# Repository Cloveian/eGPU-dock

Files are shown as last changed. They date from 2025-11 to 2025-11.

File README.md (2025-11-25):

## Goal

Create a single-board Thunderbolt 4 dock with:

* PCIe x4 GPU slot
* M.2 NVMe slot
* Lots of USB Ports
* Fast Ethernet
* 60–100 W Power Delivery (PD)
* Single voltage input

---

## Design Constraints / Features

### Wanted Features

* **Thunderbolt 4 (TB4) connection**

  * One TB4 port dedicated to PCIe tunneling for GPU
  * One TB4 port dedicated to M.2 NVMe, USB, and Ethernet
* **PCIe 4.0 x4 slot**

  * Maximum lanes available over TB4 (for GPU)
* **M.2 NVMe slot**

  * PCIe Gen4 x2
* **Power Delivery (PD)**

  * 60–100 W to laptop over TB4
* **USB Hub**

  * 4 USB-C ports
  * 4 USB-A 3.x ports
* **Single Voltage Input**

  * Powers all components: TB4 controller, USB hub, NVMe, optional GPU rails

---

## Notes / Design Considerations

* **PCIe Lane Allocation**

  * TB4 Port 1: x4 lanes → GPU
  * TB4 Port 2: x4 lanes → M.2 NVMe, USB, and Ethernet
* **Power Distribution**

  * Hub powered from 5 V regulated rail
  * NVMe powered from 3.3 V regulated rail
  * Optional GPU rails from main input if using external connector
* **High-Speed Signal Integrity**

  * Controlled impedance for PCIe and TB4 differential pairs
  * Length matching for PCIe lanes
* **Thermal Management**

  * Heatsink for ASM2464PD TB4 controllers
  * Airflow for GPU and NVMe
  * Optional fan headers
* **User QoL Features**

  * LED indicators: TB4 link, GPU detected, NVMe active, USB hub power/activity
  * Hot-plug detection and optional soft-reset for GPU/NVMe
  * Debug/test points for PCIe, USB lanes, and PD monitoring

---

## Component Selection

| Component | Model / Notes |
| --- | --- |
| TB4 Controller | 2x ASM2464PD |
| PCIe Fanout Chip (USB+2.5G MAC) | PCI11414C |
| 2.5GbE Transceiver | TBD |
| USB Hub(S) | 1x USB7216C + 1x USB7206C |
| PD+USB-C negotiation | TBD |
| Voltage Regulators | Switching / Linear as required |

<!--
[https://files.slop.gay/pub/docs/Asmedia/ASM2464PD-X/](https://files.slop.gay/pub/docs/Asmedia/ASM2464PD-X/)
-->

---

## Data Flow

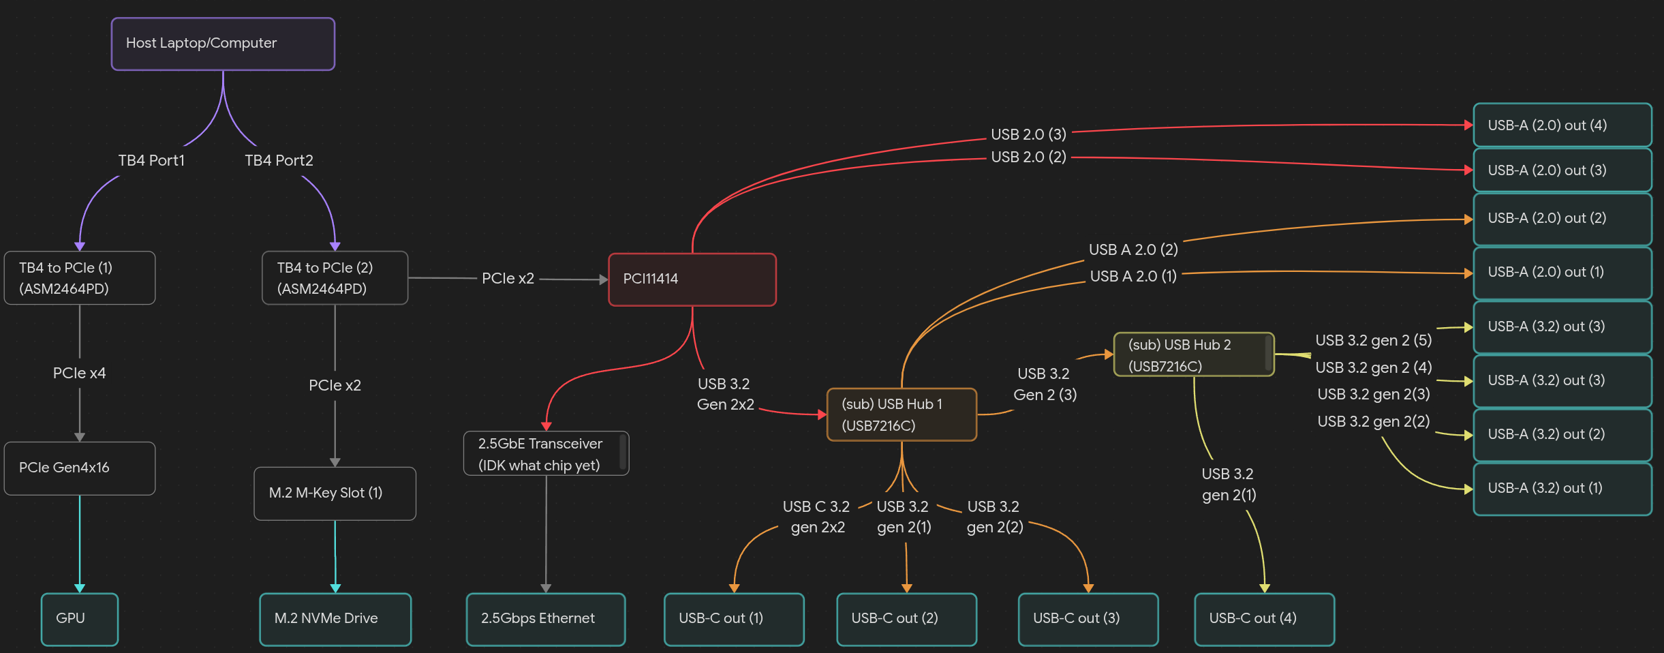
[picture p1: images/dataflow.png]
Data Flow Chart


---
<!-- 
## Electrical / Power Planning

* Input Voltage: 12–20 V (regulated for all components)
* Power Budget:

  * GPU: external connector
  * NVMe: 3.3 V / 5 V
  * USB hub: 5 V, max 900 mA per USB-A port, PD for USB-C ports
* PD Output: 60–100 W to host laptop
* Overcurrent / overvoltage protection per rail

---
-->

## Mechanical / PCB Planning

#### Layer Stackup
| Layer | Type | Primary Use | Key PI/SI Note |
|---|---|---|---|
| L1 | Signal | HS (TB4, PCIe) | Microstrip. Route shortest high-speed traces here. |
| L2 | GND | Solid Ground | Unified Ground. Primary reference for L1 & L3. |
| L3 | Signal | HS (TB4, PCIe) | Stripline. Route longest critical differential pairs. Ref: L2/L4. |
| L4 | GND | Solid Ground | Unified Ground. Shields top signals from the power core. |
| L5 | Signal | HS (USB 3.2, 2.5GbE) | Stripline. Secondary high-speed routing layer. Ref: L4/L6. |
| L6 | PWR | 12V GPU Rail | CRITICAL: Use 2 oz copper. Sandwiched by L5 & L7 GND for isolation. |
| L7 | GND | Solid Ground | Unified Ground. Isolates 12V from 5V. |
| L8 | PWR | 5V System Rail | Sandwiched by L7 & L9 GND. Consider 2 oz copper if current is high. |
| L9 | GND | Solid Ground | Unified Ground. Isolates 5V from 3.3V. |
| L10 | PWR | 3.3V Logic Rail | Sensitive. Ideal layer for small Analog Power Island split. |
| L11 | GND | Solid Ground | Unified Ground. Shields core from bottom signals. |
| L12 | Signal | LS (I2C, SPI) | Stripline. Good for noisy low-speed digital signals. |
| L13 | Signal | LS (GPIOs) | Stripline. General-purpose routing. |
| L14 | Signal | LS (Audio) | Stripline. Keep sensitive audio traces here. |
| L15 | Signal | POL Islands / Spare | Ideal for local low-voltage power islands (1.050V, 1.900V). |
| L16 | Signal | Component Breakout | Microstrip. Used for lower speed/density connections. |

---
<!--
## Notes / To-Do

* Final PCIe lane allocation plan
* USB hub layout (mix of USB-C / USB-A)
* 3D case design / airflow
* PCB stackup, layer allocation
* Component sourcing & cost analysis
* Firmware testing (hot-plug, soft-reset, PD negotiation)

---
-->

<!--
## References

* ASM2464PD datasheet
* CYUSB3304 datasheet
* TPS65987DDJ datasheet
* PCIe / Thunderbolt routing guides
* Voltage regulator datasheets

---
-->

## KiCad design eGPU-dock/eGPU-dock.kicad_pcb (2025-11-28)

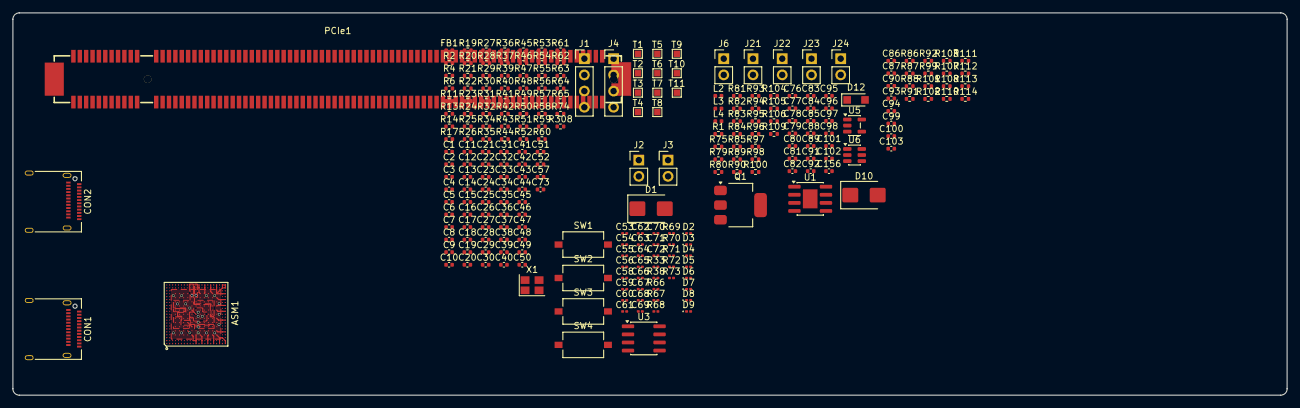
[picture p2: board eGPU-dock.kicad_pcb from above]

Board: 16 copper layers, 200.0 x 60.0 mm, 253 parts (0 on the bottom side), 145 nets.

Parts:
ASM1: ASM2464PDX
C1, C2, C3, C9, C10, C11, C15, C16, C17, C88, C89: 2.2UF/6.3V; C_0402_1005Metric
C4, C5, C6, C12, C13, C14, C18, C19, C20, C21: 10UF/6.3V; C_0402_1005Metric
C7, C78, C79: 22UF/6.3V; C_0402_1005Metric
C8, C23, C26, C27, C30, C31, C34, C35, C39: 0.22UF/10V; C_0402_1005Metric
C22, C24, C25, C28, C29, C32, C33, C36, C37, C40, C41, C42, C43, C44, C45, C46: 0.22UF/6.3V; C_0402_1005Metric
C38: 10PF/50V; C_0402_1005Metric
C47, C48: 0.22UF/16V; C_0402_1005Metric
C49, C50, C51, C52: 1UF/10V; C_0402_1005Metric
C53, C54: 220PF/50V; C_0201_0603Metric
C55, C56, C58, C59, C60, C61: 0.1UF/25V; C_0201_0603Metric
C57, C73, C81, C82, C84, C85, C92, C101, C156: 0.1UF/16V; C_0402_1005Metric
C62, C63, C64, C65, C69, C70, C71, C72: 0.33UF/25V; C_0201_0603Metric
C66, C67: 0.1UF/16V; C_0201_0603Metric
C68: 1UF/16V; C_0201_0603Metric
C76, C77: 15PF/50V; C_0402_1005Metric
C80, C83: 10UF/16V; C_0402_1005Metric
C86, C87, C90, C93, C94, C99, C100, C103: 0.22u; C_0402_1005Metric
C91: 0.1UF/50V; C_0402_1005Metric
C95, C96: 22UF/10V; C_0402_1005Metric
C97, C98: 10UF/25V; C_0402_1005Metric
C102: 3300PF/50V; C_0402_1005Metric
CON1, CON2: USB_C_Plug; USB_C_Receptacle_Amphenol_12401610E4-2A
D1, D10: SR34; D_SMB
D2, D3, D4, D5, D6, D7, D8, D9: ESD150; D_0201_0603Metric
D12: B130LAW; Nexperia_CFP3_SOD-123W
FB1: 5nF; L_0402_1005Metric
J1, J4: Conn_01x04; PinHeader_1x04_P2.54mm_Vertical
J2, J3, J6, J21, J22, J23, J24: Conn_01x02; PinHeader_1x02_P2.54mm_Vertical
L2, L3: 2.2UH; L_0402_1005Metric
L4: 10UH; L_0402_1005Metric
PCIe1: PCIexpress_x16; CONN-SMD_164P-P1.00_X1611WVS-164-9TV30
Q1: GS1117AXF; SOT-223
R1: 2.2KΩ; R_0402_1005Metric
R2: 20Ω; R_0402_1005Metric
R4, R11, R17, R19, R25, R26, R29, R31, R32, R34, R36, R37, R41, R54, R55, R59, R63, R64, R65, R74, R75, R84, R87, R88, R91, R92, R93, R94, R95, R96, R97, R99, R101, R102, R103, R104, R105, R107, R108, R110, R111, R112, R113, R114, R308: 0Ω; R_0402_1005Metric
R6, R20, R21, R24, R27, R28, R30, R81, R85, R100: 100KΩ; R_0402_1005Metric
R13, R43, R44, R45, R46, R47, R48, R49, R50, R51, R52, R53, R56, R57, R58, R61, R62: 4.7KΩ; R_0402_1005Metric
R14, R22, R23, R35: 1KΩ; R_0402_1005Metric
R33, R38: 0Ω; R_0201_0603Metric
R39, R40: 2MΩ; R_0402_1005Metric
R42: 12.1KΩ; R_0402_1005Metric
R60, R106: 10KΩ; R_0402_1005Metric
R66, R67, R68, R69, R70, R71, R72, R73: 220KΩ; R_0201_0603Metric
R79: 330KΩ; R_0402_1005Metric
R80, R89: 150KΩ; R_0402_1005Metric
R82: 165Ω; R_0402_1005Metric
R83: 100Ω; R_0402_1005Metric
R86: 4.7kΩ; R_0402_1005Metric
R90: 180KΩ; R_0402_1005Metric
R98: 28KΩ; R_0402_1005Metric
R109: 7.5KΩ; R_0402_1005Metric
SW1, SW2, SW3, SW4: SW_Push; SW_Tactile_SPST_NO_Straight_CK_PTS636Sx25SMTRLFS
T1, T2, T3, T4, T5, T6, T7, T8, T9, T10, T11: TestPoint; TestPoint_Pad_1.0x1.0mm
U1: MP2307DN; SOIC-8-1EP_3.9x4.9mm_P1.27mm_EP2.29x3mm
U3: W25X20CLSN; SOIC-8_3.9x4.9mm_P1.27mm
U5: RT8059; TSOT-23-5
U6: ID8225B-ADA60; SOT-23-6
X1: 25 Mhz; Crystal_SMD_Abracon_ABM8AIG-4Pin_3.2x2.5mm

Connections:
3V3OUT_1D: C80.2, C81.2, Q1.2 (OUT), Q1.4 (Vout), R83.1, R84.2
+1.05V_PG: R75.1, U6.5 (PG)
+3.3V: J6.1, R86.1
+3.3V_PCIE: PCIe1.A9 (+3.3V), PCIe1.A10 (+3.3V), PCIe1.B8 (+3.3V)
+5V_BUS: C82.2, C83.2, C88.2, C89.2, D1.1 (K), J2.1, Q1.3 (IN), R54.2, R55.1, R81.1, R85.1, R95.1, U5.4 (VIN), U6.4 (VIN)
+5V_BUS_CON: C55.1, C56.1, C58.1, C59.1, C60.1, C61.1, C66.2, C67.2, CON1.A4 (VBUS), CON1.A9 (VBUS), CON1.B4 (VBUS), CON1.B9 (VBUS), D1.2 (A), J2.2, R54.1, R55.2, R57.2, R94.1
+12V_AD: J23.1, R104.1
+12V_ATX: J23.2, J24.2
+12V_PCIE: PCIe1.A2 (+12V), PCIe1.A3 (+12V), PCIe1.B1 (+12V), PCIe1.B2 (+12V), PCIe1.B3 (+12V)
/GPU/GPU1/CLONE: C50.2, R27.2, R29.1, SW3.1
/GPU/GPU1/ERASE: C49.2, R24.2, R25.1, R26.1, SW1.1
/GPU/GPU1/I2C_INT_PDC: J3.1, R63.1
/GPU/GPU1/I2C_VCC_P: J4.1, R74.1
/GPU/GPU1/VBUS_CON: C68.2, R57.1, R59.2, R60.2
/GPU/GPU2/1V8_EN: C84.2, R85.2, U5.1 (EN)
/GPU/GPU2/+1.05V_EN: C85.2, R81.2, U6.1 (EN)
/GPU/GPU2/FB_1V8: C77.1, R79.2, R89.1, U5.5 (OUT)
/GPU/GPU2/FB_3V3_1D: Q1.1 (ADJ/GND), R82.1, R83.2
/GPU/GPU2/PS_ON#: C156.2, J22.1, R1.2
/GPU/GPU3/PCIe_TX0_C+: C86.2, PCIe1.B14 (PETp0)
/GPU/GPU3/PCIe_TX0_C-: C87.2, PCIe1.B15 (PETn0)
/GPU/GPU3/PCIe_TX1_C+: C90.2, PCIe1.B19 (PETp1)
/GPU/GPU3/PCIe_TX1_C-: C93.2, PCIe1.B20 (PETn1)
/GPU/GPU3/PCIe_TX2_C+: C94.2, PCIe1.B23 (PETp2)
/GPU/GPU3/PCIe_TX2_C-: C99.2, PCIe1.B24 (PETn2)
/GPU/GPU3/PCIe_TX3_C+: C100.2, PCIe1.B27 (PETp3)
/GPU/GPU3/PCIe_TX3_C-: C103.2, PCIe1.B28 (PETn3)
AD2: C95.2, C96.2, D10.2 (A), L4.2, R96.1, R97.1, R98.1
CC1: ASM1.AA6 (CC1), C54.2, R33.1
CC1_C: CON1.A5 (CC), R33.2
CC2: ASM1.Y6 (CC2), C53.2, R38.1
CC2_C: CON1.B5 (VCONN), R38.2
GND: ASM1.AA1 (GNDA), ASM1.AA2 (GNDA), ASM1.AA5 (GNDA), ASM1.AA9 (GNDA), ASM1.AA12 (GNDA), ASM1.AA14 (GNDA), ASM1.AA16 (GNDA), ASM1.AA18 (GNDA), ASM1.AA20 (GNDA), ASM1.AA21 (GNDA), ASM1.D4 (GND), ASM1.D5 (GND), ASM1.D11 (GND), ASM1.D17 (GND), ASM1.D18 (GND), ASM1.E4 (GND), ASM1.E5 (GND), ASM1.E17 (GND), ASM1.E18 (GND), ASM1.F4 (GND), ASM1.F5 (GND), ASM1.F8 (GND), ASM1.F17 (GND), ASM1.F18 (GND), ASM1.H4 (GND), ASM1.H8 (GND), ASM1.H17 (GND), ASM1.H18 (GND), ASM1.J4 (GND), ASM1.J5 (GND), ASM1.J6 (GND), ASM1.J11 (GND), ASM1.K2 (GND), ASM1.L1 (GNDA), ASM1.L2 (GNDA), ASM1.L4 (GNDA), ASM1.L5 (GNDA), ASM1.L9 (GND), ASM1.L13 (GND), ASM1.M20 (GNDA), ASM1.M21 (GNDA), ASM1.N1 (GNDA), ASM1.N2 (GNDA), ASM1.N4 (GNDA), ASM1.N5 (GNDA), ASM1.N9 (GND), ASM1.N11 (GND), ASM1.N13 (GND), ASM1.N17 (GNDA), ASM1.N18 (GNDA), ASM1.P4 (GNDA), ASM1.P5 (GNDA), ASM1.P9 (GND), ASM1.P11 (GND), ASM1.P17 (GNDA), ASM1.P18 (GNDA), ASM1.P20 (GNDA), ASM1.P21 (GNDA), ASM1.R1 (GNDA), ASM1.R2 (GNDA), ASM1.T4 (GNDA), ASM1.T5 (GNDA), ASM1.T17 (GNDA), ASM1.T18 (GNDA), ASM1.T20 (GNDA), ASM1.T21 (GNDA), ASM1.U1 (GNDA), ASM1.U2 (GNDA), ASM1.U4 (GNDA), ASM1.U5 (GNDA), ASM1.U17 (GNDA), ASM1.U18 (GNDA), ASM1.V4 (GNDA), ASM1.V5 (GNDA), ASM1.V6 (GNDA), ASM1.V8 (GNDA), ASM1.V9 (GNDA), ASM1.V11 (GNDA), ASM1.V13 (GNDA), ASM1.V14 (GNDA), ASM1.V16 (GNDA), ASM1.V17 (GNDA), ASM1.V18 (GNDA), ASM1.V20 (GNDA), ASM1.V21 (GNDA), ASM1.W1 (GNDA), ASM1.W2 (GNDA), ASM1.Y3 (GNDA), ASM1.Y5 (GNDA), ASM1.Y9 (GNDA), ASM1.Y12 (GNDA), ASM1.Y14 (GNDA), ASM1.Y16 (GNDA), ASM1.Y18 (GNDA), ASM1.Y20 (GNDA), ASM1.Y21 (GNDA), C1.2, C2.2, C3.2, C4.2, C5.2, C6.2, C7.2, C8.2, C9.2, C10.2, C11.2, C12.2, C13.2, C14.2, C15.2, C16.2, C17.2, C18.2, C19.2, C20.2, C21.1, C22.2, C23.2, C24.2, C25.2, C26.2, C27.2, C28.2, C29.2, C30.2, C31.2, C32.2, C33.2, C34.2, C35.2, C36.2, C37.2, C39.2, C40.2, C41.2, C42.2, C43.2, C44.2, C45.2, C46.2, C47.1, C48.1, C49.1, C50.1, C51.1, C52.1, C53.1, C54.1, C55.2, C56.2, C57.1, C58.2, C59.2, C60.2, C61.2, C66.1, C67.1, C68.1, C73.1, C76.1, C78.1, C79.1, C80.1, C81.1, C82.1, C83.1, C84.1, C85.1, C88.1, C89.1, C92.2, C95.1, C96.1, C97.1, C98.1, C101.1, C156.1, CON1.A1 (GND), CON1.A12 (GND), CON1.B1 (GND), CON1.B12 (GND), D2.2 (A2), D3.2 (A2), D4.2 (A2), D5.2 (A2), D6.2 (A2), D7.2 (A2), D8.2 (A2), D9.2 (A2), D12.2 (A), FB1.2, J1.2, J3.2, J4.2, J22.2, PCIe1.A4 (GND), PCIe1.A12 (GND), PCIe1.A15 (GND), PCIe1.A18 (GND), PCIe1.A20 (GND), PCIe1.A23 (GND), PCIe1.A24 (GND), PCIe1.A27 (GND), PCIe1.A28 (GND), PCIe1.A31 (GND), PCIe1.A34 (GND), PCIe1.A37 (GND), PCIe1.A38 (GND), PCIe1.A41 (GND), PCIe1.A42 (GND), PCIe1.A45 (GND), PCIe1.A46 (GND), PCIe1.A49 (GND), PCIe1.A51 (GND), PCIe1.A54 (GND), PCIe1.A55 (GND), PCIe1.A58 (GND), PCIe1.A59 (GND), PCIe1.A62 (GND), PCIe1.A63 (GND), PCIe1.A66 (GND), PCIe1.A67 (GND), PCIe1.A70 (GND), PCIe1.A71 (GND), PCIe1.A74 (GND), PCIe1.A75 (GND), PCIe1.A78 (GND), PCIe1.A79 (GND), PCIe1.A82 (GND), PCIe1.B4 (GND), PCIe1.B7 (GND), PCIe1.B13 (GND), PCIe1.B16 (GND), PCIe1.B18 (GND), PCIe1.B21 (GND), PCIe1.B22 (GND), PCIe1.B25 (GND), PCIe1.B26 (GND), PCIe1.B29 (GND), PCIe1.B32 (GND), PCIe1.B35 (GND), PCIe1.B36 (GND), PCIe1.B39 (GND), PCIe1.B40 (GND), PCIe1.B43 (GND), PCIe1.B44 (GND), PCIe1.B47 (GND), PCIe1.B49 (GND), PCIe1.B52 (GND), PCIe1.B53 (GND), PCIe1.B56 (GND), PCIe1.B57 (GND), PCIe1.B60 (GND), PCIe1.B61 (GND), PCIe1.B64 (GND), PCIe1.B65 (GND), PCIe1.B68 (GND), PCIe1.B69 (GND), PCIe1.B72 (GND), PCIe1.B73 (GND), PCIe1.B76 (GND), PCIe1.B77 (GND), PCIe1.B80 (GND), R2.1, R13.2, R14.2, R22.2, R23.2, R35.2, R39.1, R40.2, R42.1, R45.2, R46.2, R47.2, R48.2, R49.2, R50.2, R51.2, R52.2, R53.2, R56.2, R58.2, R60.1, R66.1, R67.1, R68.1, R69.1, R70.1, R71.1, R72.1, R73.1, R82.2, R89.2, R90.2, R99.1, R105.2, R106.2, R109.1, SW1.2, SW2.2, SW3.2, SW4.2, U1.4 (GND1), U1.9 (GND2), U3.4 (GND), U5.2 (GND), U6.2 (GND), X1.2, X1.4
GPIO0: ASM1.D1 (NVMeACTLED1/GPIO0), R17.2
GPIO1: ASM1.C1 (I2C_INT/GPIO1), R63.2
GPIO2: ASM1.B1 (PRSNT#/GPIO2), R25.2
GPIO3: ASM1.A1 (NVMeACTLED2/GPIO3), C51.2, R19.2, R28.2, SW4.1
GPIO14: ASM1.A20 (CLKREQ1#/GPIO14), R45.1, T4.1
GPIO19: ASM1.A10 (PRSNT1#/GPIO19), R47.1, T5.1
GPIO20: ASM1.A11 (HDDPC1/GPIO20), R49.1, T6.1
GPIO21: ASM1.A12 (PRSNT2#/GPIO21), R51.1, T7.1
GPIO22: ASM1.A13 (PE_WAKE#/GPIO22), R29.2, R52.1
GPIO23: ASM1.A14 (CLKREQ2#/GPIO23), R53.1, T9.1
GPIO24: ASM1.A15 (CLKREQ3#/GPIO24), R56.1, T10.1
GPIO27: ASM1.A18 (PRSNT3#/GPIO27), R26.2, R58.1, T11.1
HDDPC: ASM1.C21 (HDDPC), R11.2, R13.1
HDDPC_C: C21.2, R6.2, R11.1, R14.1, R93.2
I2C_CLK_P1: J4.4, R65.1
I2C_CLK_PD: ASM1.E1 (I2C_CLK_P), R65.2
I2C_DATA_P1: J4.3, R64.1
I2C_DATA_PD: ASM1.F1 (I2C_DATA_P), R64.2
unnamed: C57.2, R41.1
unnamed: C102.1, R109.2
unnamed: CON1.S1 (SHIELD), FB1.1, R2.2
unnamed: D10.1 (K), J6.2, R96.2, R97.2
unnamed: C91.1, D12.1 (K), L4.1, U1.3 (SW)
unnamed: J1.1, R34.1
unnamed: PCIe1.A17 (PERn0), R108.1
unnamed: PCIe1.A22 (PERn1), R101.1
unnamed: PCIe1.A26 (PERn2), R112.1
unnamed: PCIe1.A30 (PERn3), R114.1
unnamed: PCIe1.A16 (PERp0), R107.1
unnamed: PCIe1.A21 (PERp1), R110.1
unnamed: PCIe1.A25 (PERp2), R111.1
unnamed: PCIe1.A29 (PERp3), R113.1
unnamed: PCIe1.A13 (REFCLK+), R102.1
unnamed: PCIe1.A14 (REFCLK-), R103.1
unnamed: PCIe1.B5 (SMCLK), R88.2
unnamed: PCIe1.B6 (SMDAT), R91.2
unnamed: PCIe1.B17 (~PRSNT2), R86.2, R87.2
unnamed: PCIe1.B11 (~WAKE), R92.2
unnamed: C91.2, U1.1 (BS)
unnamed: C101.2, C102.2, U1.6 (COMP)
unnamed: R93.1, R100.2, R105.1, U1.7 (EN)
unnamed: R98.2, R106.1, U1.5 (FB)
unnamed: C97.2, C98.2, R94.2, R95.2, R104.2, U1.2 (IN)
unnamed: C92.1, U1.8 (SS)
unnamed: R62.2, U3.7 (~HOLD)
unnamed: R61.1, U3.3 (~WP)
unnamed: L2.1, U5.3 (SW)
unnamed: R80.2, R90.1, U6.6 (FB)
unnamed: L3.1, U6.3 (SW)
PCIe_PRSNT1: PCIe1.A1 (~PRSNT1), R99.2
PERST_B: ASM1.G21 (PERST0#), C47.2, R20.2, R22.1
PERST_B1: ASM1.F21 (NC/PERST1#), T1.1
PERST_B2: ASM1.E21 (NC/PERST2#), C48.2, R21.2, R23.1
PERST_B3: ASM1.D21 (NC/PERST3#), T2.1
PRX0+: ASM1.N21 (PRXP0), R107.2
PRX0-: ASM1.N20 (PRXN0), R108.2
PRX1+: ASM1.W21 (PRXP1), R110.2
PRX1-: ASM1.W20 (PRXN1), R101.2
PRX2+: ASM1.Y19 (PRXP2), R111.2
PRX2-: ASM1.AA19 (PRXN2), R112.2
PRX3+: ASM1.AA13 (PRXP3), R113.2
PRX3-: ASM1.Y13 (PRXN3), R114.2
PTX0+: ASM1.R20 (PTXP0), C86.1
PTX0-: ASM1.R21 (PTXN0), C87.1
PTX1+: ASM1.U20 (PTXP1), C90.1
PTX1-: ASM1.U21 (PTXN1), C93.1
PTX2+: ASM1.Y17 (PTXP2), C94.1
PTX2-: ASM1.AA17 (PTXN2), C99.1
PTX3+: ASM1.Y15 (PTXP3), C100.1
PTX3-: ASM1.AA15 (PTXN3), C103.1
REFCLK0+: ASM1.AA8 (REFCLKP0), R102.2
REFCLK0-: ASM1.Y8 (REFCLKN0), R103.2
RST: ASM1.H1 (RST#), C52.2, R30.2, R35.1, R75.2, SW2.1
SBU1: ASM1.K1 (SBU1), R36.1
SBU1_C: CON1.A8 (SBU1), R36.2, R40.1
SBU2: ASM1.J1 (SBU2), R37.2
SBU2_C: CON1.B8 (SBU2), R37.1, R39.2
SPI_CLK: ASM1.A5 (GPIO6/SPI_CLK), U3.6 (CLK)
SPI_CS#: ASM1.A2 (GPIO4/SPI_CS#), U3.1 (~CS)
SPI_DI: ASM1.A4 (GPIO7/SPI_DI), U3.5 (DI/IO_{0})
SPI_DO: ASM1.A3 (GPIO5/SPI_DO), R43.1, R48.1, U3.2 (DO/IO_{1})
TEST_EN: ASM1.H21 (TEST_EN), R50.1
UART_RX: ASM1.A21 (PRSNT0#/UART_RX), J1.4, R308.2, T3.1
UART_TX: ASM1.B21 (MEMREPAIR/UART_TX), J1.3, R41.2, R44.1, R46.1
UD+: ASM1.M1 (UDP), R31.1
UD+_C: CON1.A6 (D+), R31.2
UD-: ASM1.M2 (UDM), R32.2
UD-_C: CON1.A7 (D-), R32.1
UREXT: ASM1.AA3 (REXT), R42.2
URX0+: ASM1.P1 (URXP0), C62.1
URX0+_CON: C62.2, CON1.B10 (RX1-), D7.1 (A1), R71.2
URX0-: ASM1.P2 (URXN0), C63.1
URX0-_CON: C63.2, CON1.B11 (RX1+), D9.1 (A1), R73.2
URX1+: ASM1.Y2 (URXP1), C64.1
URX1+_CON: C64.2, CON1.A10 (RX2-), D6.1 (A1), R70.2
URX1-: ASM1.Y1 (URXN1), C65.1
URX1-_CON: C65.2, CON1.A11 (RX2+), D8.1 (A1), R72.2
UTX0+: ASM1.T1 (UTXP0), C69.1
UTX0+_CON: C69.2, CON1.A3 (TX1-), D3.1 (A1), R67.2
UTX0-: ASM1.T2 (UTXN0), C70.1
UTX0-_CON: C70.2, CON1.A2 (TX1+), D5.1 (A1), R69.2
UTX1+: ASM1.V2 (UTXP1), C71.1
UTX1+_CON: C71.2, CON1.B3 (TX2-), D2.1 (A1), R66.2
UTX1-: ASM1.V1 (UTXN1), C72.1
UTX1-_CON: C72.2, CON1.B2 (TX2+), D4.1 (A1), R68.2
VBUS: ASM1.G1 (VBUS), R59.1
VCC18: ASM1.L6 (VCCL), ASM1.L16 (VCCL), ASM1.L17 (VCCL), ASM1.L18 (VCCL), ASM1.L20 (VCCL), ASM1.L21 (VCCL), ASM1.N6 (VCCL), ASM1.N16 (VCCL), ASM1.P6 (VCCL), ASM1.P16 (VCCL), ASM1.T6 (VCCL), ASM1.T16 (VCCL), ASM1.U6 (VCCL), ASM1.U11 (VCCL), ASM1.U13 (VCCL), ASM1.U14 (VCCL), ASM1.U16 (VCCL), C2.1, C5.1, C10.1, C13.1, C17.1, C20.1, C25.1, C29.1, C33.1, C37.1, C41.1, C43.1, C45.1, C46.1, C77.2, C78.2, L2.2, R79.1
VCC33_SYS: ASM1.D6 (VCCH), ASM1.D8 (VCCH), ASM1.D9 (VCCH), ASM1.D13 (VCCH), ASM1.E6 (VCCH), ASM1.E8 (VCCH), ASM1.E9 (VCCH), ASM1.E13 (VCCH), ASM1.F6 (VCCH), ASM1.F13 (VCCH), ASM1.H6 (VCCH), C3.1, C6.1, C11.1, C14.1, C16.1, C19.1, C23.1, C27.1, C31.1, C35.1, C73.2, J21.2, R4.2, R6.1, R20.1, R21.1, R24.1, R27.1, R28.1, R30.1, R34.2, R43.2, R44.2, R61.2, R62.1, R74.2, R84.1, R100.1, U3.8 (VCC)
VCCA33: ASM1.H5 (VCCA33), C7.1, C8.1, R4.1
VDD095: ASM1.D14 (VDD), ASM1.D16 (VDD), ASM1.E11 (VDD), ASM1.E14 (VDD), ASM1.E16 (VDD), ASM1.F9 (VDD), ASM1.F11 (VDD), ASM1.F14 (VDD), ASM1.F16 (VDD), ASM1.H9 (VDD), ASM1.H11 (VDD), ASM1.H13 (VDD), ASM1.H14 (VDD), ASM1.H16 (VDD), ASM1.J8 (VDD), ASM1.J9 (VDD), ASM1.J13 (VDD), ASM1.J14 (VDD), ASM1.J16 (VDD), ASM1.J17 (VDD), ASM1.J18 (VDD), ASM1.J20 (VDD), ASM1.J21 (VDD), ASM1.K20 (VDD), ASM1.K21 (VDD), ASM1.L8 (VDD), ASM1.L11 (VDD), ASM1.L14 (VDD), ASM1.N8 (VDD), ASM1.N14 (VDD), ASM1.P8 (VDD), ASM1.P13 (VDD), ASM1.P14 (VDD), ASM1.T8 (VDD), ASM1.T9 (VDD), ASM1.T11 (VDD), ASM1.T13 (VDD), ASM1.T14 (VDD), ASM1.U8 (VDD), ASM1.U9 (VDD), C1.1, C4.1, C9.1, C12.1, C15.1, C18.1, C22.1, C24.1, C26.1, C28.1, C30.1, C32.1, C34.1, C36.1, C39.1, C40.1, C42.1, C44.1, C76.2, C79.2, L3.2, R80.1
XI: C38.2, X1.3
XO: ASM1.Y4 (XO), C38.1, X1.1

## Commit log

2025-11-18 kicad files
    [eGPU-dock.kicad_pcb, eGPU-dock.kicad_sch]
2025-11-19 update kicad
    [eGPU-dock.kicad_pcb, eGPU-dock.kicad_sch]
2025-11-20 add footprint+datasheets
2025-11-20 fix symbol
    [AQR113-Pins.csv]
2025-11-20 finish symbol and footprint
    [eGPU-dock.kicad_sch]
2025-11-21 add diagram and stuff
    [eGPU-dock.kicad_sch]
2025-11-25 clean up
    [AQR113-Pins.csv, eGPU-dock.kicad_sch]
2025-11-27 masive schamatic update
    [GPU.kicad_sch, GPU1.kicad_sch, GPU2.kicad_sch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]
2025-11-28 almost as masive schematic update
    [GPU.kicad_sch, GPU1.kicad_sch, GPU2.kicad_sch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]
